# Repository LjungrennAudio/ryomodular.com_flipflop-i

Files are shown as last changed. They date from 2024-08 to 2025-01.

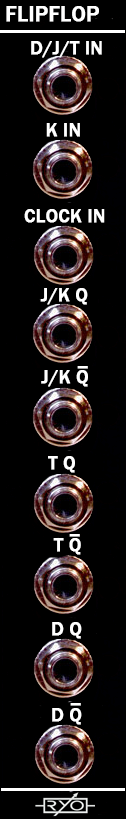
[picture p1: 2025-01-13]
docs/flipflop.png

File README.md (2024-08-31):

# ryomodular.com_flipflop-i
 one of multiplesets of designings for flipflop modules to be consolidated

2408310052

this is just one of multiple flipflop ideas ive seen saved so someehow ive gotta consolidate em all - first thing is to get em all in one place, so why not gihub - is as good as any other /shrug?

i hope this isnt the peak of what i remember of fliplop designs cos i really love flipflops and want to do them justice...

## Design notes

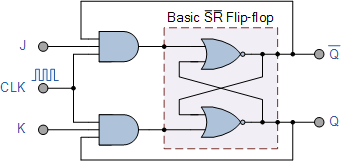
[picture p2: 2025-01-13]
docs/sequential-seq47.gif

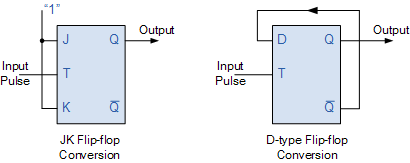
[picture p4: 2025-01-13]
docs/Conversion of Flip-flops from one flip-flop to Another_files/sequential-seq49.gif

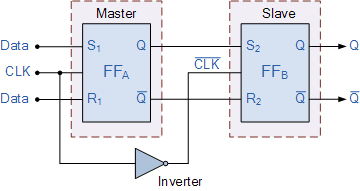
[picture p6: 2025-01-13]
docs/Conversion of Flip-flops from one flip-flop to Another_files/sequential-seq48.gif

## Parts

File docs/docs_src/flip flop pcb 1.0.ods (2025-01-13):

RYO Flipflop 1.0
Qty | Value | Parts | Note
4 | 100k | R26, R27, R28, R29 | 3.5mm
14 | 100k | R3, R4, R5, R6, R7, R8, R9, R10, R11, R12, R19, R21, R23, R25 | 7mm
9 | 1k | R13, R14, R15, R16, R17, R30, R31, R32, R33 | 3.5mm
4 | 1k | R18, R20, R22, R24 | 7mm
2 | 10R | R1, R2 | 7mm 1/4W
4 | 15pF | C12, C13, C14, C15
8 | 100nF | C1, C2, C5, C6, C7, C9, C10, C11
1 | 100uF | C8
2 | 10uF | C3, C4
4 | 1N4148 | D3, D4, D5, D6
2 | 1N5818 | D1, D2
1 | LM2931 5V | RG1
1 | LM324 | IC4
2 | CD40106 | IC1, IC2
1 | CD4013 | IC3
2 | 10 pin strip angled | CON1, CON2
1 | 2x5 pin keyed header | POWER
9 | 3.5MM JACK | J1, J2, J3, J4, J5, J6, J7, J8, J9 | Erthenvar jack.
5 | green | L1, L2, L3, L6, L7 | 3mm
4 | orange | L4, L5, L8, L9 | 3mm
1 | Power Cable
2 | Mounting screws
1 | PCB set
1 | Panel

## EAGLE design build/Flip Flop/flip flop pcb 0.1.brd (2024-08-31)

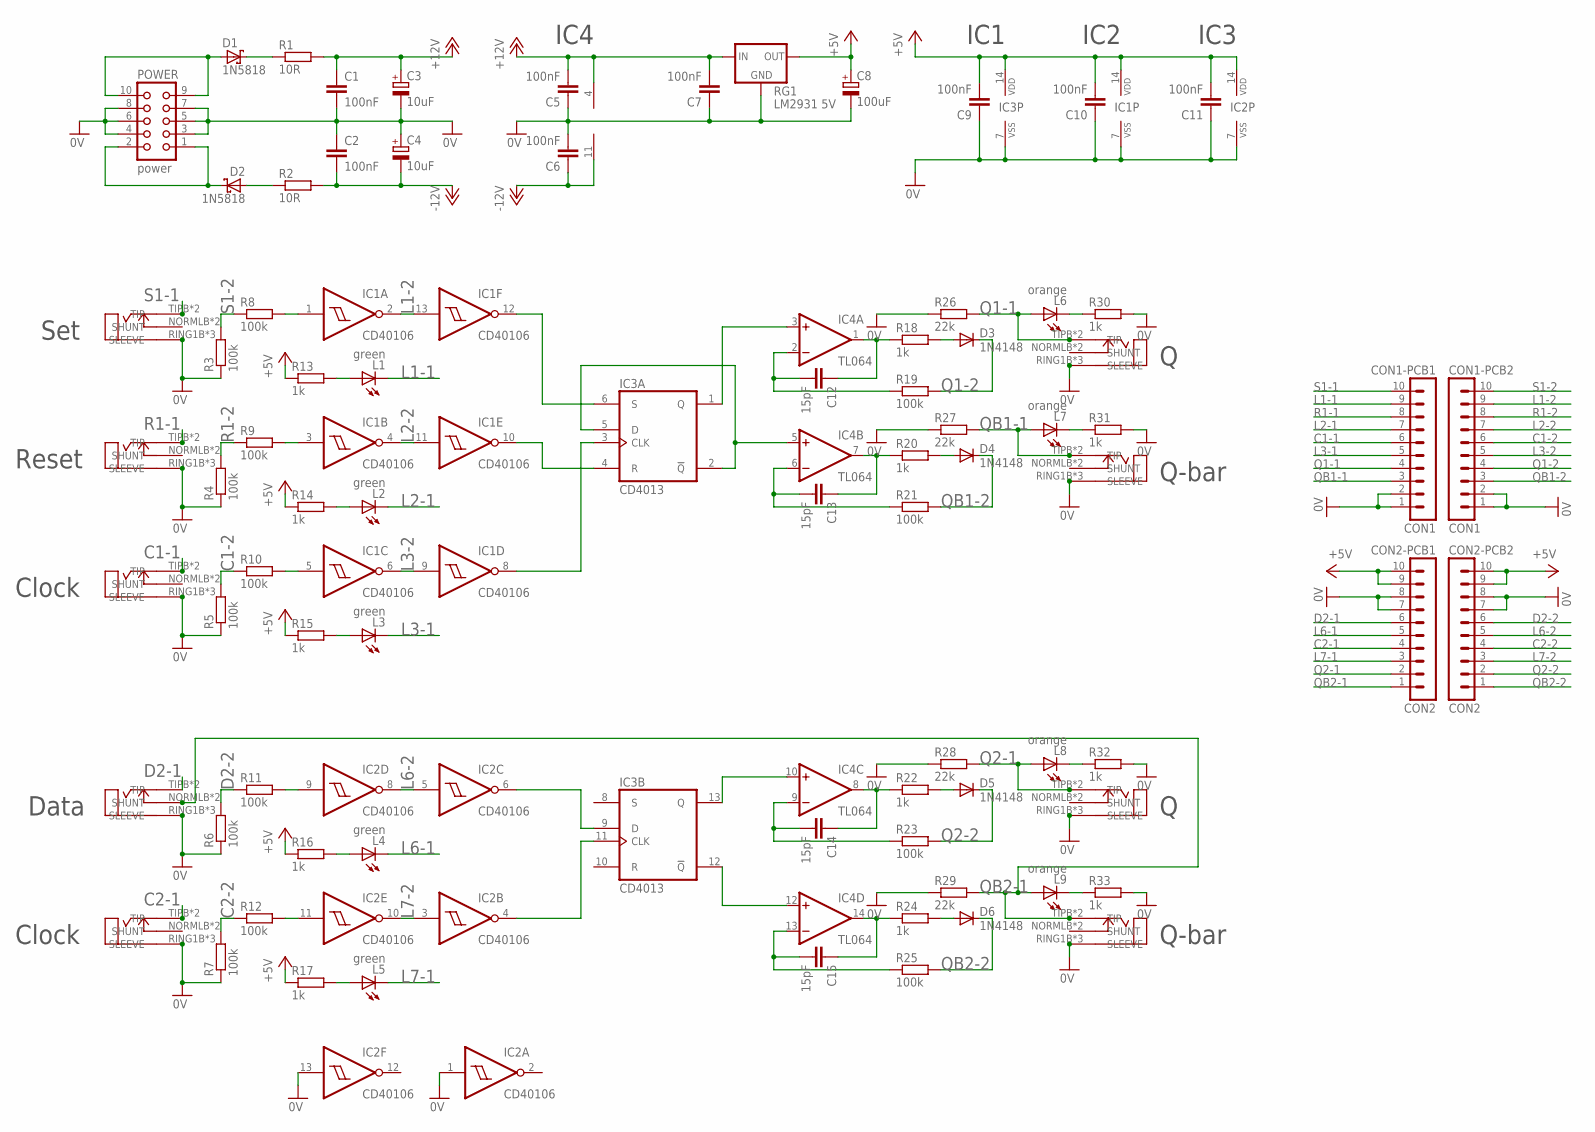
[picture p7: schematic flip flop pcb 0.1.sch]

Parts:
C1, C2, C5, C6, C7, C9, C10, C11: 100nF; C025-024X044
C3, C4: 10uF; E2-5
C8: 100uF; E2,5-6
C12, C13, C14, C15: 15pF; C025-024X044
CON1-PCB1, CON1-PCB2: CON1; MA10-1
CON2-PCB1, CON2-PCB2: CON2; MA10-1
D1, D2: 1N5818; DO41-7
D3, D4, D5, D6: 1N4148; DO35-7
IC1, IC2: CD40106; DIL14
IC3: CD4013; DIL14
IC4: TL064; DIL14
J1, J2, J3, J4, J5, J6, J7, J8, J9: ERTHENVAR_3.5MM_JACKSLOTS; ERTHENVAR-SLOTS
L1, L2, L3, L4, L5: green; LED3MM
L6, L7, L8, L9: orange; LED3MM
POWER: power; CON10L
R1, R2: 10R; 0207/9
R3, R4, R5, R6, R7, R8, R9, R10, R11, R12, R19, R21, R23, R25: 100k; 0207/9
R13, R14, R15, R16, R17, R30, R31, R32, R33: 1k; 0204/5
R18, R20, R22, R24: 1k; 0207/9
R26, R27, R28, R29: 22k; 0204/5
RG1: LM2931 5V; TO92-LINE

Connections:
0V: C1.2, C2.1, C3.-, C4.+, C5.1, C6.2, C7.1, C8.-, C9.1, C10.1, C11.1, CON1-PCB1.1, CON1-PCB1.2, CON1-PCB2.1, CON1-PCB2.2, CON2-PCB1.7, CON2-PCB1.8, CON2-PCB2.7, CON2-PCB2.8, IC1.7 (VSS), IC2.1 (I), IC2.7 (VSS), IC2.13 (I), IC3.7 (VSS), J1.RING1B (SLEEVE), J1.RING1T (SLEEVE), J1.RING2H (SLEEVE), J2.RING1B (SLEEVE), J2.RING1T (SLEEVE), J2.RING2H (SLEEVE), J3.RING1B (SLEEVE), J3.RING1T (SLEEVE), J3.RING2H (SLEEVE), J4.RING1B (SLEEVE), J4.RING1T (SLEEVE), J4.RING2H (SLEEVE), J5.RING1B (SLEEVE), J5.RING1T (SLEEVE), J5.RING2H (SLEEVE), J6.RING1B (SLEEVE), J6.RING1T (SLEEVE), J6.RING2H (SLEEVE), J7.RING1B (SLEEVE), J7.RING1T (SLEEVE), J7.RING2H (SLEEVE), J8.RING1B (SLEEVE), J8.RING1T (SLEEVE), J8.RING2H (SLEEVE), J9.RING1B (SLEEVE), J9.RING1T (SLEEVE), J9.RING2H (SLEEVE), POWER.3, POWER.4, POWER.5, POWER.6, POWER.7, POWER.8, R3.1, R4.1, R5.1, R6.1, R7.1, R26.1, R27.1, R28.1, R29.1, R30.2, R31.2, R32.2, R33.2, RG1.2 (GND)
+5V: C8.+, C9.2, C10.2, C11.2, CON2-PCB1.9, CON2-PCB1.10, CON2-PCB2.9, CON2-PCB2.10, IC1.14 (VDD), IC2.14 (VDD), IC3.14 (VDD), R13.1, R14.1, R15.1, R16.1, R17.1, RG1.3 (OUT)
+12V: C1.1, C3.+, C5.2, C7.2, IC4.4 (V+), R1.2, RG1.1 (IN)
-12V: C2.2, C4.-, C6.1, IC4.11 (V-), R2.2
C1-1: CON1-PCB1.6, J3.TIPB (TIP), J3.TIPT (TIP)
C1-2: CON1-PCB2.6, R5.2, R10.1
C2-1: CON2-PCB1.4, J5.TIPB (TIP), J5.TIPT (TIP)
C2-2: CON2-PCB2.4, R7.2, R12.1
D2-1: CON2-PCB1.6, J4.TIPB (TIP), J4.TIPT (TIP)
D2-2: CON2-PCB2.6, R6.2, R11.1
L1-1: CON1-PCB1.9, L1.K (C)
L1-2: CON1-PCB2.9, IC1.2 (O), IC1.13 (I)
L2-1: CON1-PCB1.7, L2.K (C)
L2-2: CON1-PCB2.7, IC1.4 (O), IC1.11 (I)
L3-1: CON1-PCB1.5, L3.K (C)
L3-2: CON1-PCB2.5, IC1.6 (O), IC1.9 (I)
L6-1: CON2-PCB1.5, L4.K (C)
L6-2: CON2-PCB2.5, IC2.5 (I), IC2.8 (O)
L7-1: CON2-PCB1.3, L5.K (C)
L7-2: CON2-PCB2.3, IC2.3 (I), IC2.10 (O)
unnamed: IC1.1 (I), R8.2
unnamed: IC3.2 (!Q), IC3.5 (D), IC4.5 (+IN)
unnamed: IC1.3 (I), R9.2
unnamed: IC1.5 (I), R10.2
unnamed: IC2.9 (I), R11.2
unnamed: IC2.11 (I), R12.2
unnamed: IC1.12 (O), IC3.6 (S)
unnamed: IC1.10 (O), IC3.4 (R)
unnamed: IC1.8 (O), IC3.3 (CLK)
unnamed: IC2.4 (O), IC3.11 (CLK)
unnamed: IC2.6 (O), IC3.9 (D)
unnamed: IC3.1 (Q), IC4.3 (+IN)
unnamed: C12.2, IC4.2 (-IN), R19.1
unnamed: C12.1, IC4.1 (OUT), R18.1
unnamed: D3.A, R18.2
unnamed: C13.2, IC4.6 (-IN), R21.1
unnamed: C13.1, IC4.7 (OUT), R20.1
unnamed: D4.A, R20.2
unnamed: IC3.13 (Q), IC4.10 (+IN)
unnamed: IC3.12 (!Q), IC4.12 (+IN)
unnamed: C15.2, IC4.13 (-IN), R25.1
unnamed: C15.1, IC4.14 (OUT), R24.1
unnamed: D6.A, R24.2
unnamed: D1.C, R1.1
unnamed: C14.2, IC4.9 (-IN), R23.1
unnamed: C14.1, IC4.8 (OUT), R22.1
unnamed: D5.A, R22.2
unnamed: D1.A, POWER.9, POWER.10
unnamed: D2.C, POWER.1, POWER.2
unnamed: D2.A, R2.1
unnamed: L1.A, R13.2
unnamed: L2.A, R14.2
unnamed: L3.A, R15.2
unnamed: L6.K (C), R30.1
unnamed: L7.K (C), R31.1
unnamed: L4.A, R16.2
unnamed: L5.A, R17.2
unnamed: L8.K (C), R32.1
unnamed: L9.K (C), R33.1
Q1-1: CON1-PCB1.4, J6.TIPB (TIP), J6.TIPT (TIP), L6.A, R26.2
Q1-2: CON1-PCB2.4, D3.C, R19.2
Q2-1: CON2-PCB1.2, J8.TIPB (TIP), J8.TIPT (TIP), L8.A, R28.2
Q2-2: CON2-PCB2.2, D5.C, R23.2
QB1-1: CON1-PCB1.3, J7.TIPB (TIP), J7.TIPT (TIP), L7.A, R27.2
QB1-2: CON1-PCB2.3, D4.C, R21.2
QB2-1: CON2-PCB1.1, J4.NORMLB (SHUNT), J4.NORMLT (SHUNT), J9.TIPB (TIP), J9.TIPT (TIP), L9.A, R29.2
QB2-2: CON2-PCB2.1, D6.C, R25.2
R1-1: CON1-PCB1.8, J2.TIPB (TIP), J2.TIPT (TIP)
R1-2: CON1-PCB2.8, R4.2, R9.1
S1-1: CON1-PCB1.10, J1.TIPB (TIP), J1.TIPT (TIP)
S1-2: CON1-PCB2.10, R3.2, R8.1

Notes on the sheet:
Set
Reset
Data
Clock
Q-bar
IC4
IC1
IC2
IC3

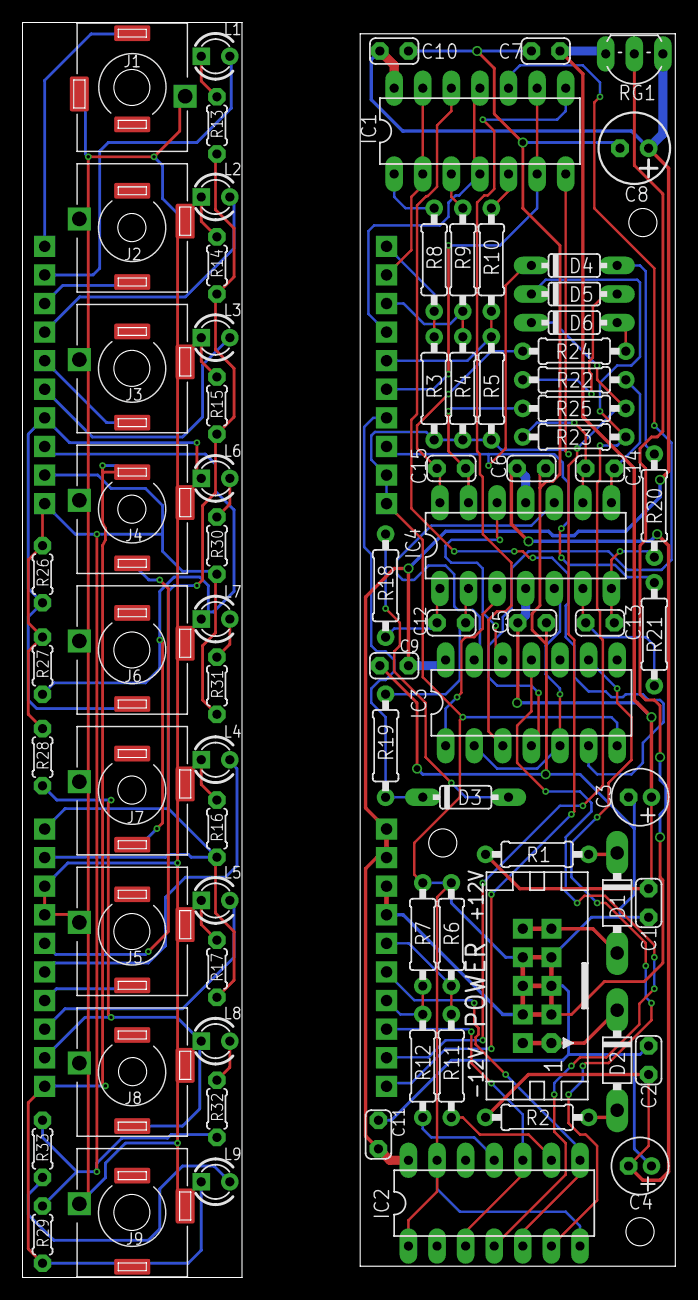
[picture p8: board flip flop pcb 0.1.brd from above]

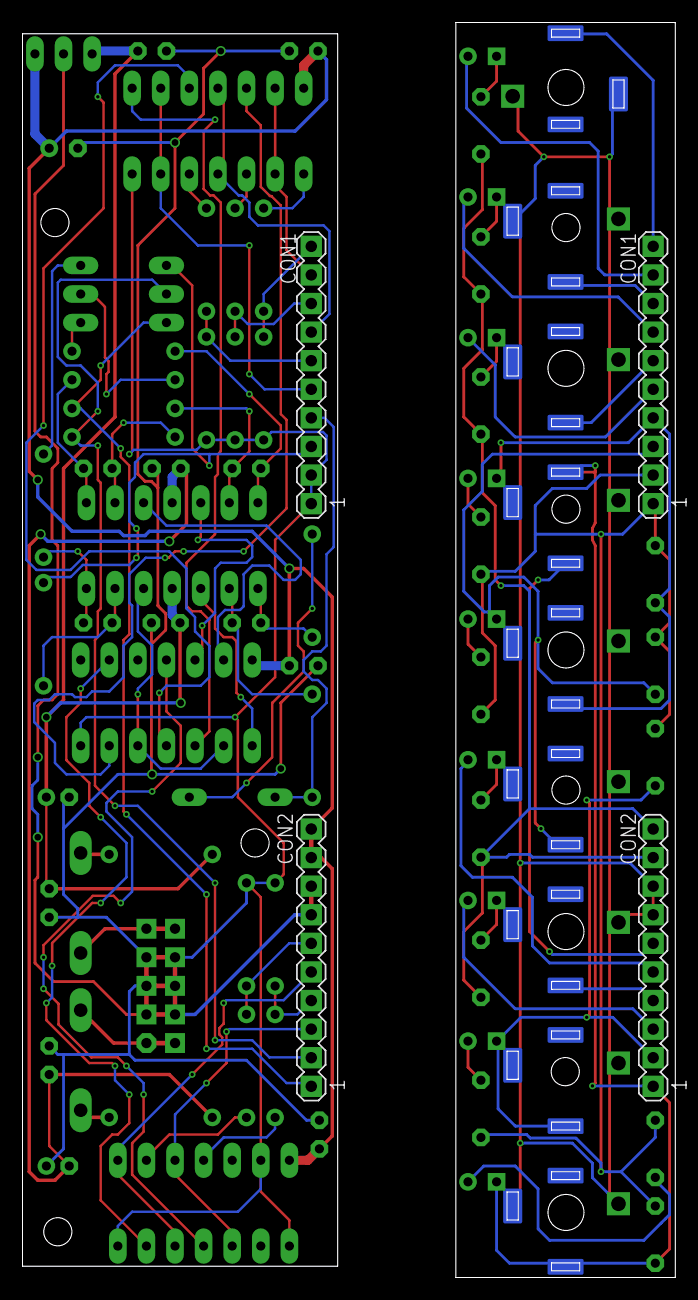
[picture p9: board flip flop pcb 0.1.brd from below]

Board: 2 copper layers, 58.0 x 111.5 mm, 82 parts (4 on the bottom side), 71 nets.
